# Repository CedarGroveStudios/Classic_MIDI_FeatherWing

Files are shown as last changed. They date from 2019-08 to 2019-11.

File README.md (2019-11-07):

# Classic_MIDI_FeatherWing

### _A classic MIDI interface FeatherWing with provisions for DIN-5 and TRS TypeB connectors_

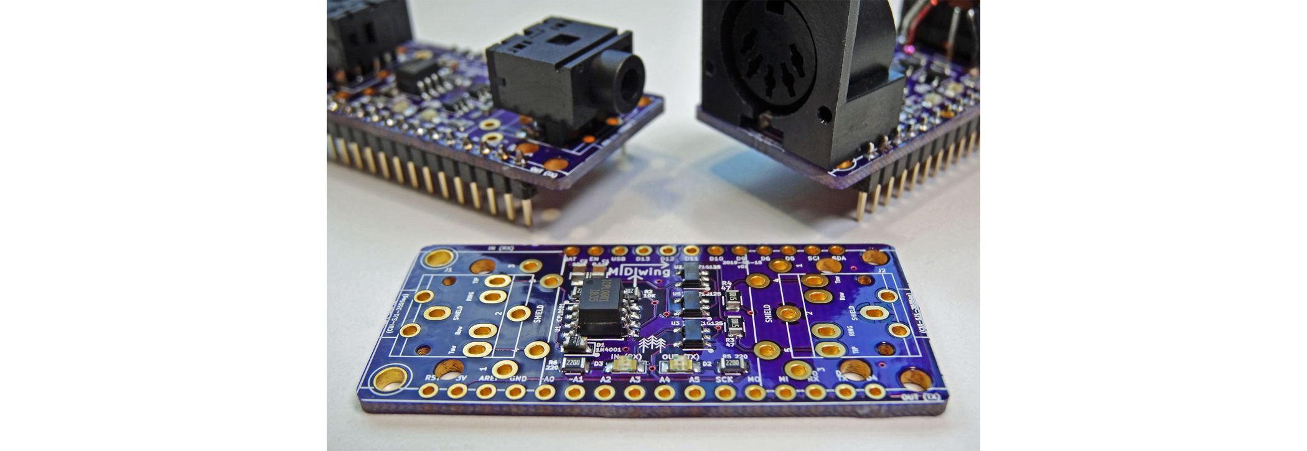
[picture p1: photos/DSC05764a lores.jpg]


The Classic MIDI FeatherWing interface is an Adafruit Feather-compatible module. Deriving its power from the host Feather's 3.3V power, the interface converts incoming and outgoing classic MIDI current-loop input and output to Feather UART (RX and TX) logic pins.

The wing provides on-board input and output footprints for 3.5mm TRS Type B and DIN-5 connectors while maintaining the Feather dimensional format, thanks to John Park's inspirational _Feather MIDI Nub_ design (Twitter: @johnedgarpark). The MIDI input is an optically-isolated connection. MIDI output is buffered and current-limited. On-board receive (RX) and transmit (TX) LEDs indicate incoming and outgoing signals.

To use the wing as a standalone MIDI interface, see the UART-STEMMA MIDI Backpack project: https://github.com/CedarGroveStudios/UART-STEMMA_MIDI_Backpack

DIN-5 MIDI jack used: https://www.adafruit.com/product/1134

3.5mm TRS MIDI jack used: https://www.adafruit.com/product/1699

The Classic MIDI interface was tested with CircuitPython version 4.1.0 beta 1 and earlier releases. Example code is provided in the repository. Additional code examples can be found within the _adafruit__midi_ CircuitPython examples distribution.

OSH Park project: https://oshpark.com/shared_projects/SzjsJUV0

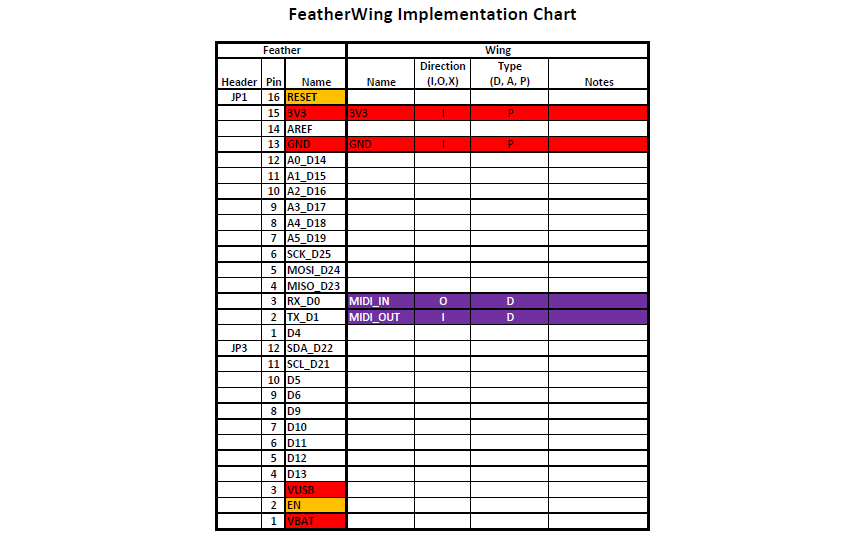
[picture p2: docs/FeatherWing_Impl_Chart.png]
FeatherWing Implementation Chart


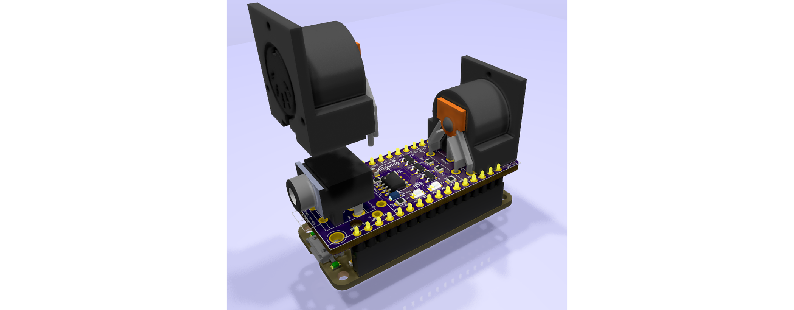
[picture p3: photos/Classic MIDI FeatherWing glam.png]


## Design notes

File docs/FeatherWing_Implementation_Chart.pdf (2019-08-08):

Feather | Wing
Header | Pin | Name | Name | Direction (I,O,X) | Type (D, A, P) | Notes
JP1 | 16 | RESET
| 15 | 3V3 | 3V3 | I | P
| 14 AREF
| 13 | GND | GND | I | P
| 12 A0_D14
| 11 A1_D15
| 10 A2_D16
| 9 A3_D17
| 8 A4_D18
| 7 A5_D19
| 6 SCK_D25
| 5 MOSI_D24
| 4 MISO_D23
| 3 | RX_D0 | MIDI_IN | O | D
| 2 | TX_D1 | MIDI_OUT | I | D
| 1 D4
JP3 | 12 | SDA_D22
| 11 SCL_D21
| 10 D5
| 9 D6
| 8 D9
| 7 D10
| 6 D11
| 5 D12
| 4 D13
| 3 VUSB
| 2 EN
| 1 VBAT

## FeatherWing Implementation Chart

8/7/2019 4:58 PM | FeatherWing_Implementation_Chart.xlsx FeatherWing Impl Chart | Page 1 of 1

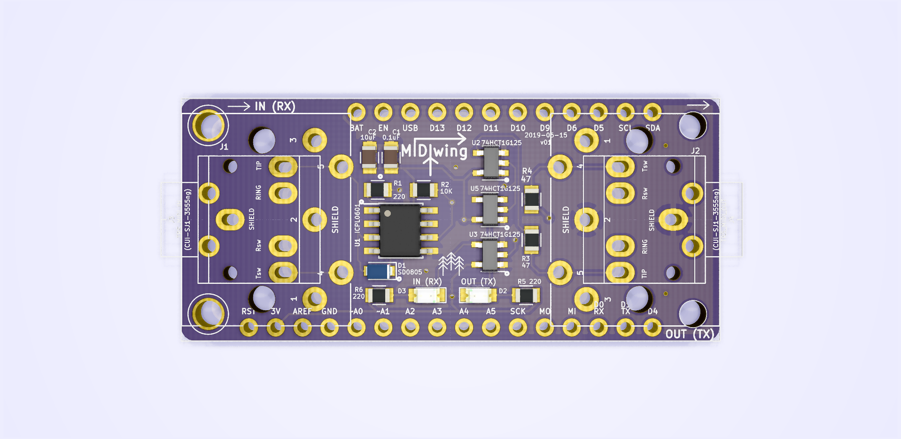
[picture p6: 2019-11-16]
photos/Classic MIDI FeatherWing_board.png

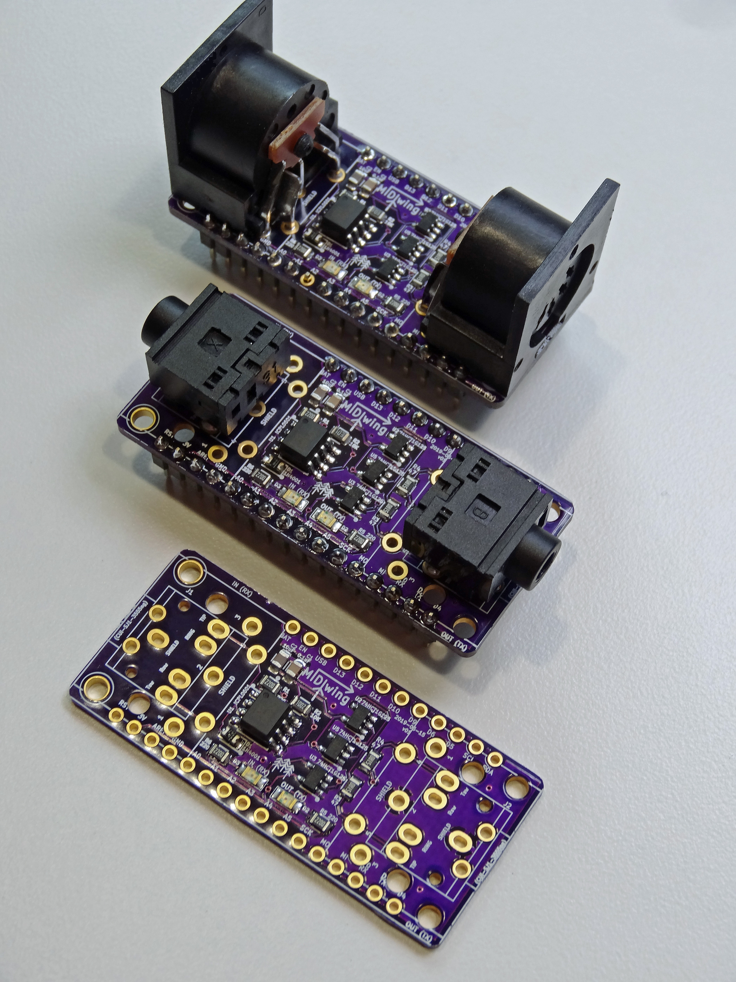
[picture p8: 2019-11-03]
photos/DSC05755a lores-orig.jpg

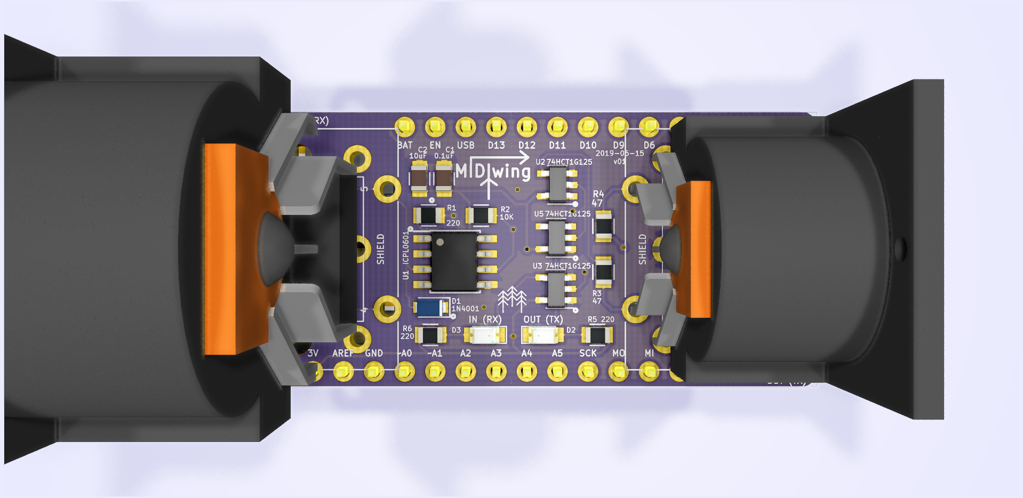
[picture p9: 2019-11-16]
photos/Classic MIDI FeatherWing.png

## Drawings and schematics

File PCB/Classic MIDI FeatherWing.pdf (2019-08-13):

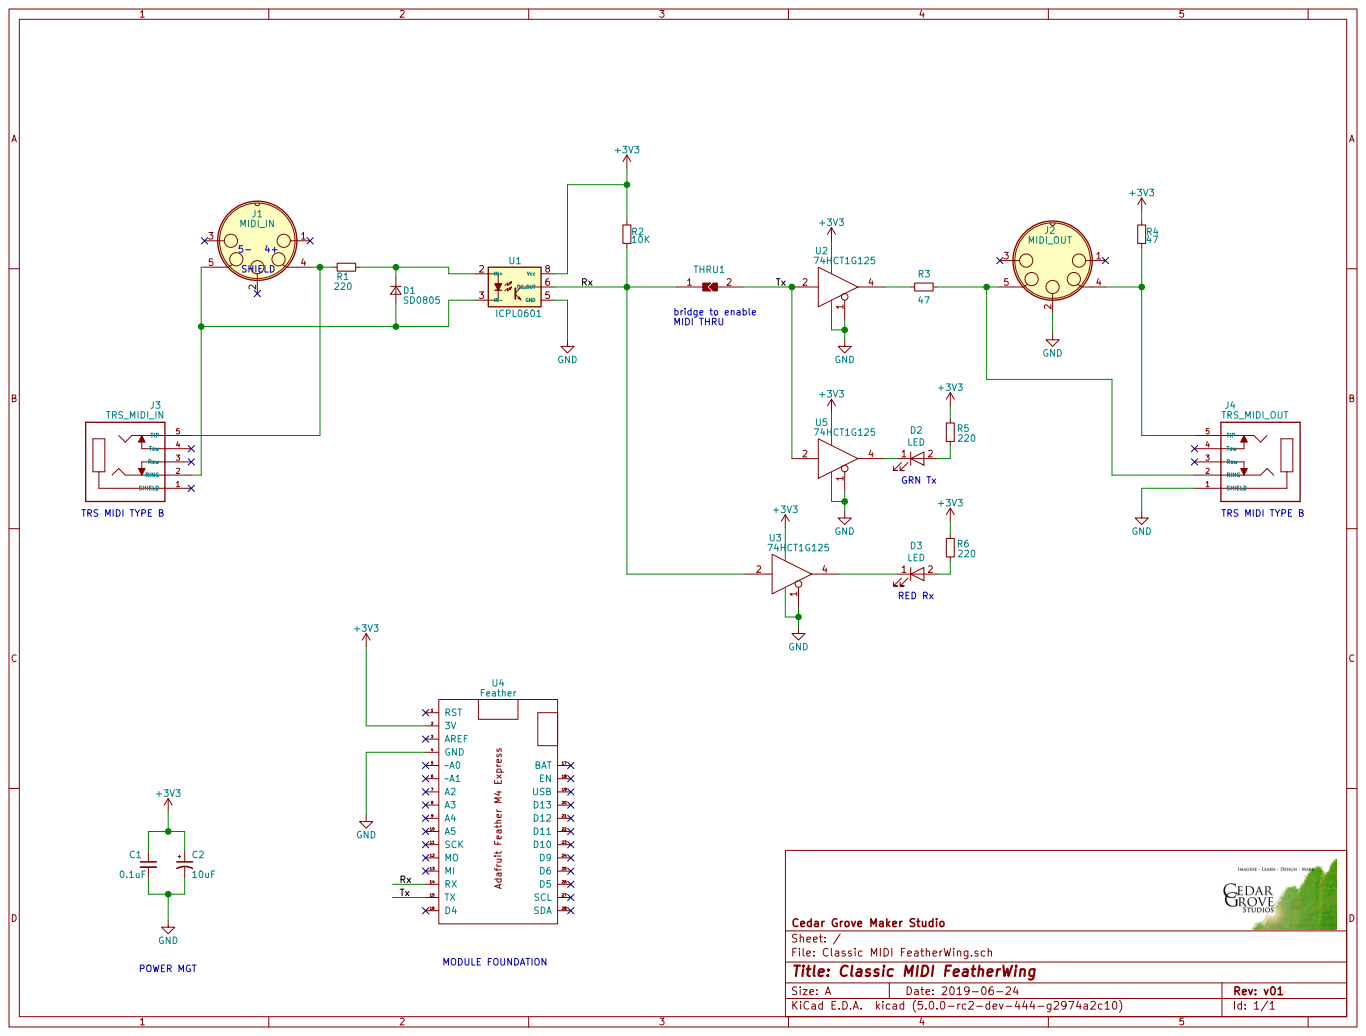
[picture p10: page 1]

220 GRN Tx RED Rx bridge to enable MIDI THRU

File: Classic MIDI FeatherWing.sch Sheet: / Cedar Grove Maker Studio

Id: 1/1 Title: Classic MIDI FeatherWing

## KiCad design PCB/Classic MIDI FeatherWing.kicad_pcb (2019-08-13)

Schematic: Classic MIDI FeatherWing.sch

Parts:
C1: 0.1uF; C_0805_HandSoldering
C2: 10uF; C_0805_HandSoldering
D1: 1N4001; D_0805_hand_soldering
D2, D3: LED; LED_0805_HandSoldering
J1: MIDI_IN; CUI_SDS-50J
J2: MIDI_OUT; CUI_SDS-50J
J3: TRS_MIDI_IN; STX-3120-5_3.5mm
J4: TRS_MIDI_OUT; STX-3120-5_3.5mm
R1, R5, R6: 220; R_0805_HandSoldering
R2: 10K; R_0805_HandSoldering
R3, R4: 47; R_0805_HandSoldering
THRU1: Solder_Jumper_0805; 0805_Solder_Jumper
U1: ICPL0601; SOIC-8_3.9x4.9mm_Pitch1.27mm
U2, U3, U5: 74HCT1G125; TSOP-5_1.65x3.05mm_Pitch0.95mm_hand_solder
U4: Feather; Adafruit_Feather_M4_Express_bare

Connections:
+3V3: C1.1, C2.1, R2.1, R4.1, R5.2, R6.2, U1.8 (Vcc), U2.6, U3.6, U4.2, U5.6
/Rx: R2.2, THRU1.1, U1.6 (OC_OUT), U3.2, U4.14
/Tx: THRU1.2, U2.2, U4.15, U5.2
GND: C1.2, C2.2, J2.2, J4.1, U1.5 (GND), U2.1, U2.3, U3.1, U3.3, U4.4, U5.1, U5.3
unnamed: D1.1, R1.2, U1.2 (IN+)
unnamed: D1.2, J1.5, J3.2, U1.3 (IN-)
unnamed: D2.1, U5.4
unnamed: D2.2, R5.1
unnamed: D3.1, U3.4
unnamed: D3.2, R6.1
unnamed: J1.4, J3.5, R1.1
unnamed: J2.4, J4.5, R4.2
unnamed: J2.5, J4.2, R3.1
unnamed: R3.2, U2.4

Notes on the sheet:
SHIELD
POWER MGT
MODULE FOUNDATION
GRN Tx
RED Rx
bridge to enable MIDI THRU
TRS MIDI TYPE B

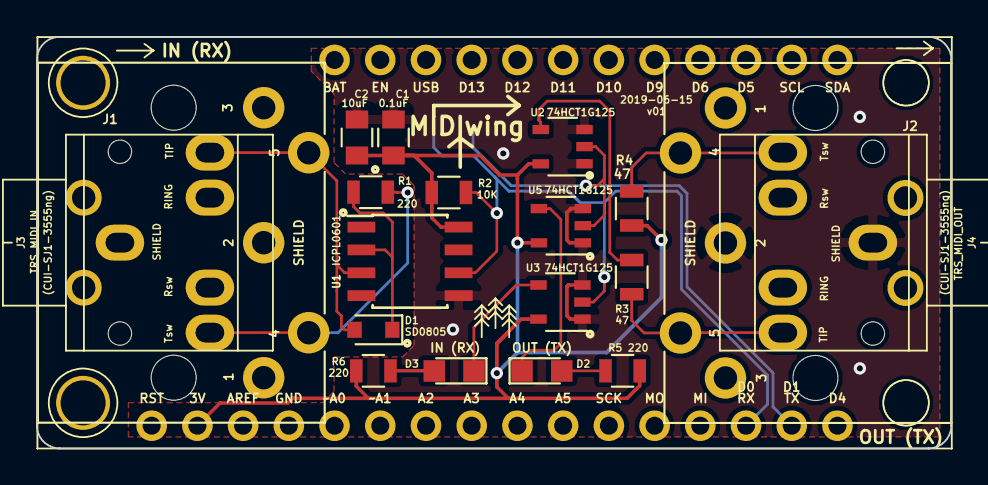
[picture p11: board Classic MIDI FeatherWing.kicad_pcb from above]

Board: 2 copper layers, 50.8 x 22.9 mm, 21 parts (1 on the bottom side), 14 nets.

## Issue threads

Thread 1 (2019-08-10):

sourcing D1

hajdbo, 2019-08-10:
D1 1N4001 is a through-hole ref, and the smallest close match I found (general purpose 50V 1A) is a SOD123F, which does not fit the footprint.

Can you point to a ref #?

CedarGroveStudios, 2019-08-12:
Sorry about that. I've been using an SD0805S040S0R5 (40v 0.5A Schottky), DigiKey #478-7802-1-ND
[https://www.digikey.com/products/en?keywords=478-7802-1-ND](url)

hajdbo, 2019-08-13:
thank you!

Closed 2019-08-13.

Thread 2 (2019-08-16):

Getting closer to spec?

hajdbo, 2019-08-16:
While trying to debug MIDI between my nRF52840 feather express and a Novation Circuit, I noted:
- The MIDI spec for 3.3V says R4 should be changed from 47Ω to 33Ω (1/2W), and R3 from 47Ω to 10Ω.

- the 74HCT1G125 spec says Vcc min is 4.5V, but is driven at 3.3V. Ref: https://assets.nexperia.com/documents/data-sheet/74HC_HCT1G125.pdf

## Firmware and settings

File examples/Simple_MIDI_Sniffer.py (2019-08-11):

# Simple_MIDI_Sniffer.py
# for Classic MIDI FeatherWing
# 2019-08-10 Cedar Grove Studios
# based upon @kevinjwalter's adafruit_midi library and examples
#

import time
# import usb_midi
import adafruit_midi
import busio
import board

from adafruit_midi.timing_clock            import TimingClock
from adafruit_midi.channel_pressure        import ChannelPressure
from adafruit_midi.control_change          import ControlChange
from adafruit_midi.note_off                import NoteOff
from adafruit_midi.note_on                 import NoteOn
from adafruit_midi.pitch_bend              import PitchBend
from adafruit_midi.polyphonic_key_pressure import PolyphonicKeyPressure
from adafruit_midi.program_change          import ProgramChange
from adafruit_midi.start                   import Start
from adafruit_midi.stop                    import Stop
from adafruit_midi.system_exclusive        import SystemExclusive
from adafruit_midi.midi_message            import MIDIUnknownEvent

from cedargrove_MIDI_util                  import *

UART = busio.UART(board.TX, board.RX, baudrate=31250, timeout=0.001)
midi = adafruit_midi.MIDI(midi_in=UART, midi_out=UART, in_channel=0, out_channel=0)
# 0 is MIDI channel 1

print("Simple_MIDI_Sniffer.py 2019-08-10 CedarGrove")
# Convert channel numbers at the presentation layer to the ones musicians use
print("Input channel:", midi.in_channel + 1 )

midi_thru = False  # True to enable MIDI Thru
tempo_show = False  # True to enable tempo calculation
t0 = time.monotonic_ns()
tempo = 0

while True:

    msg = midi.receive()

    if msg is not None:
        if midi_thru:
            midi.send(msg)  # MIDI thru
        if isinstance(msg, NoteOn):
            print("NoteOn:")
            print("#%02d %s %5.3fHz" % (msg.note, note_lexo(msg.note), note_freq(msg.note)))
            print(" vel %03d  chan #%02d" %(msg.velocity, msg.channel + 1))

        elif isinstance(msg, NoteOff):
            print("NoteOff:")
            print("#%02d %s %5.3fHz" % (msg.note, note_lexo(msg.note), note_freq(msg.note)))
            print(" vel %03d  chan #%02d" %(msg.velocity, msg.channel + 1))

        elif isinstance(msg, TimingClock):
            if tempo_show:
                t1 = time.monotonic_ns()
                if (t1-t0) != 0:
                    tempo = (tempo + (1 / ((t1 - t0) * 24) * 60 * 1e9)) / 2 # simple running average
                    print("-Tick: %03.1f BPM" % tempo)  # compared to previous tick
                t0 = time.monotonic_ns()
            else: print("-Tick")  # compared to previous tick

        elif isinstance(msg, ChannelPressure):
            print("ChannelPressure: ")
            print(" press %03d  chan #%02d" %(msg.pressure, msg.channel + 1))

        elif isinstance(msg, ControlChange):
            print("ControlChange: ctrl #%03d  %s" % (msg.control, cc_decoder(msg.control)))
            print(" value %03d  chan #%02d" %(msg.value, msg.channel + 1))

        elif isinstance(msg, PitchBend):
            print("PitchBend: ")
            print(" bend %05d  chan #%02d" %(msg.pitch_bend, msg.channel + 1))

        elif isinstance(msg, PolyphonicKeyPressure):
            print("PolyphonicKeyPressure:")
            print(" #%02d %s %5.3fHz" % (msg.note, note_lexo(msg.note), note_freq(msg.note)))
            print(" press %03d  chan #%02d" %(msg.pressure, msg.channel + 1))

        elif isinstance(msg, ProgramChange):
            print("ProgramChange:")
            print(" patch %03d  chan #%02d" %(msg.patch, msg.channel + 1))

        elif isinstance(msg, (Start, Stop)): print("-- %s --" % str(type(msg))[8:-2])

        elif isinstance(msg, SystemExclusive):
            print("SystemExclusive:  ID= ", msg.manufacturer_id,
                ", data= ", msg.data)
            print("--------------------")

        elif isinstance(msg, MIDIUnknownEvent):
            # Message are only known if they are imported
            print("Unknown MIDI event status ", msg.status)

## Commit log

2019-07-30 fix fast tempo error
    [Simple_MIDI_Sniffer.py]
2019-08-08 update repo structure
    [Classic MIDI FeatherWing.kicad_pcb, Classic MIDI FeatherWing.sch, FeatherWing_Implementation_Chart.xlsx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]
2019-08-13 update schematic and add BOM spreadsheet
    [Classic_MIDI_FeatherWing_BOM.xlsx]
2019-08-13 update silkscreen
    [Classic MIDI FeatherWing-B.Cu.gbl, Classic MIDI FeatherWing-B.Mask.gbs, Classic MIDI FeatherWing-B.SilkS.gbo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]
2021-07-12 update documentation
    [Classic_MIDI_FeatherWing_BOM.xlsx, FeatherWing_Implementation_Chart.xlsx]
